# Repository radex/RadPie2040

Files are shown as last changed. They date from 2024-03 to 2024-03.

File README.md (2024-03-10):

# RadPie2040

A RP2040-based board, similar to [Raspberry Pi Pico H](https://www.raspberrypi.com/products/raspberry-pi-pico/), featuring:

- RP2040 microcontroller
- 16MB Flash
- breadboard-friendly pin headers with labels (+ debug header)
- USB-C connector
- BOOTSEL *and* RESET buttons
- **JLCPCB Assembly optimized**, 2-layer board
- KiCad 8 template, hierarchical schematic

**DISCLAIMER**: This board was designed as an exercise. It has not (yet) been manufactured and tested. Also, **I don't know what I'm doing**, this is like the third PCB I've designed. Don't use it lol.

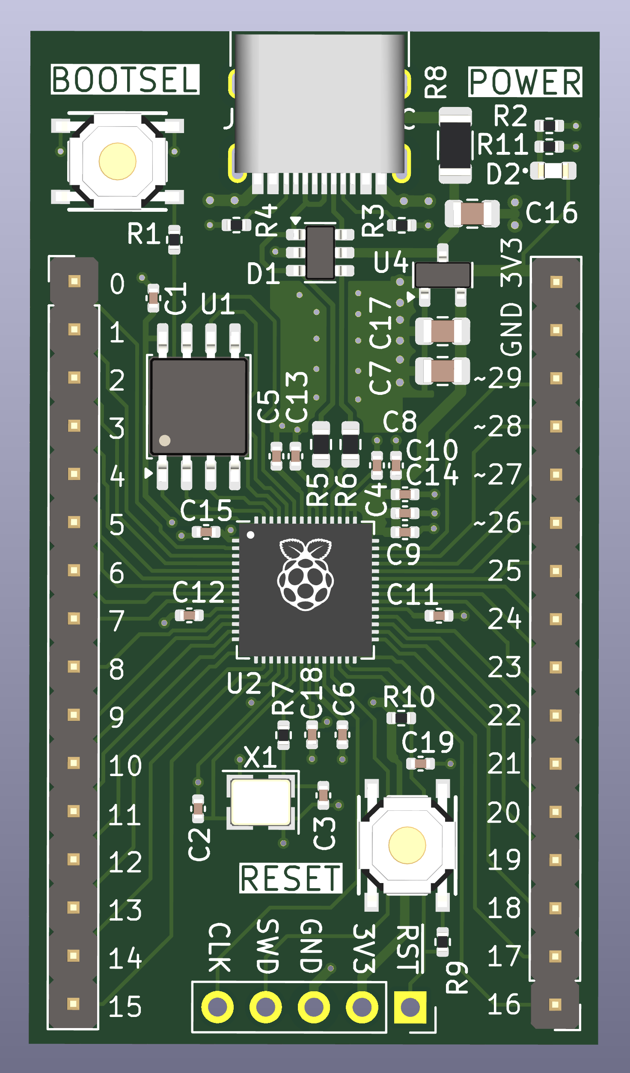
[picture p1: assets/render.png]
Top down render of the board
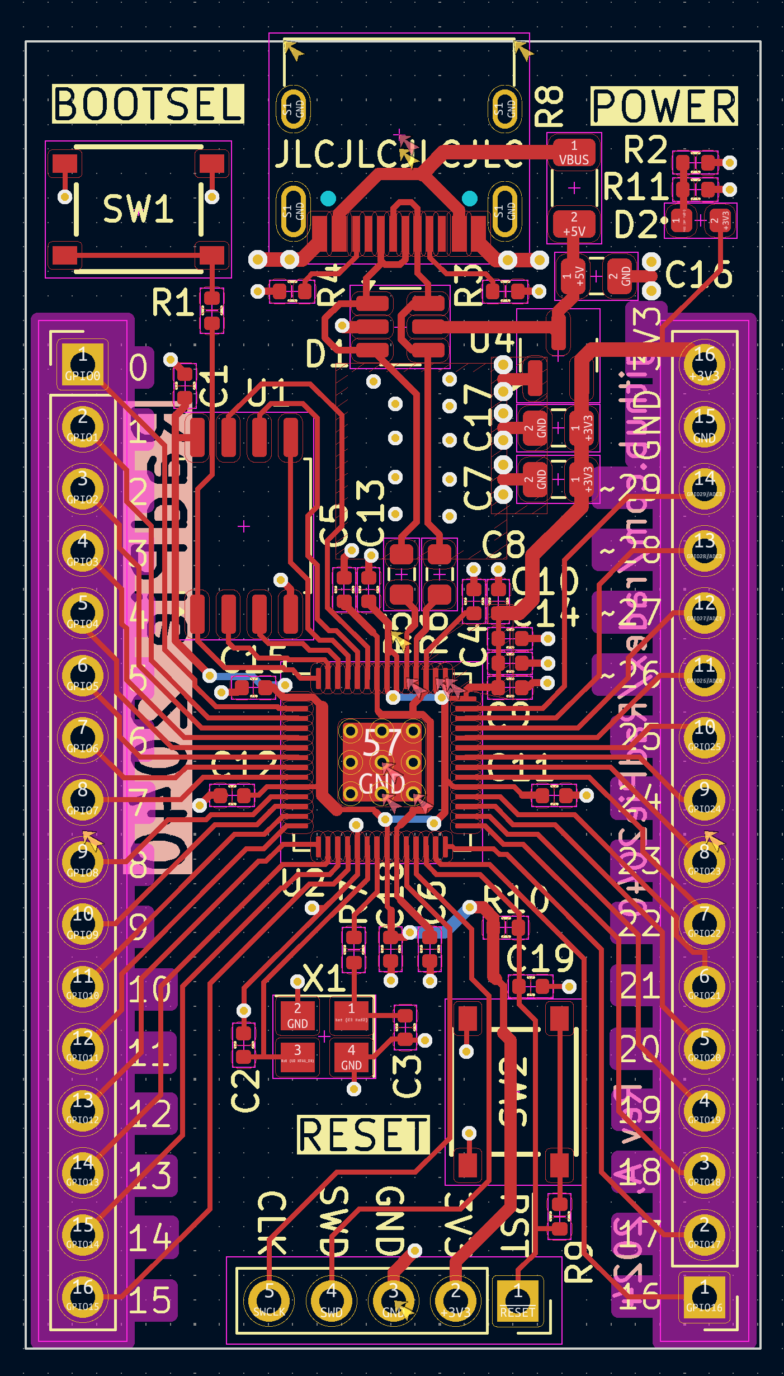
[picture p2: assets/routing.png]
PCB routing
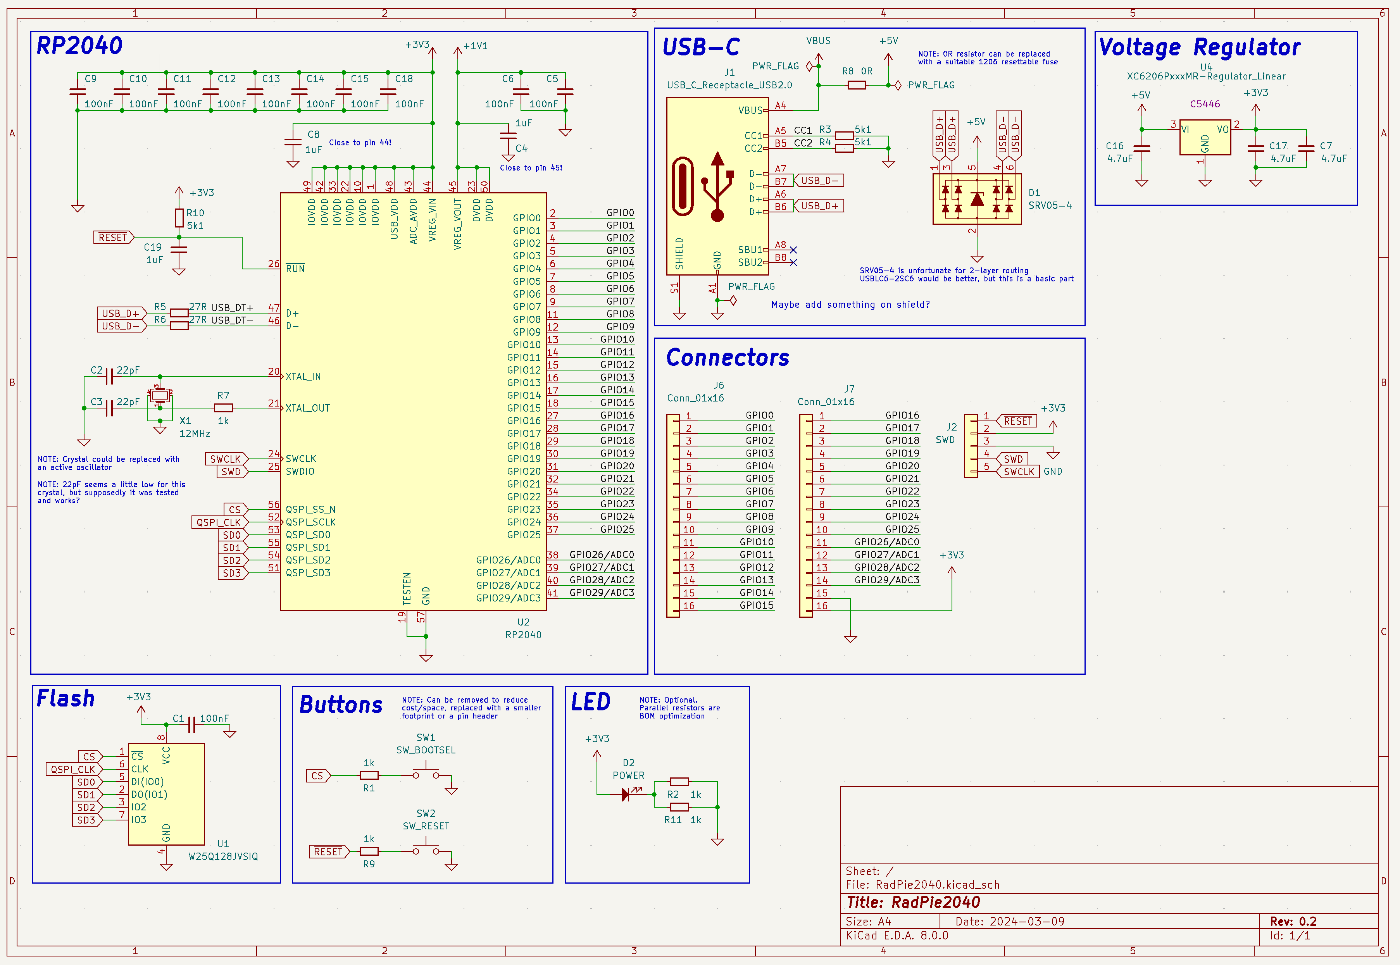
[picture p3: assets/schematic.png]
Schematics
|  |  |  |
| -- | -- | -- |

## Credits and learning resources

This project is a fork of [Sleepdealr/RP2040-designguide](https://github.com/Sleepdealr/RP2040-designguide). It bears little resemblance to the original, but it was a great starting point (and still contains some pieces of it).

I also took a lot of inspiration and knowledge from these YouTube videos:

- [MicroType Engineering - RP2040 KiCad 6 Hardware Design](https://www.youtube.com/watch?v=RNH-CL8GrF8)
- [Phil’s Lab - Raspberry Pi RP2040 Hardware Design](https://www.youtube.com/watch?v=X00Cm5LMNQk)

There's extra learning resources in the `Resources/` folder (copied from Sleepdealr's project).

## Components

This board is optimized to use JLCPCB Basic (or Extended Preferred) components as much as possible to make it cheap to manufacture at 2-5 pieces scale.

Some worth mentioning:

- Flash: C97521 - Winbond W25Q128JVSIQ - 128Mbit (16MB) NOR Flash
- Voltage Regulator: C5446 - XC6206
- Crystal: C9002 - 12MHz
- Buttons: C318884 - TS-1187A-B-A-B
- TVS diodes: C7420376 - SRV05-4

Most components are the same as in [Sleepdealr's design](https://github.com/Sleepdealr/RP2040-designguide). Differences: larger Flash, different TVS diodes, added buttons, power LED indicator, removed resettable fuse.

**Extended parts**: The only parts that are not on JLCPCB's Basic parts list (i.e. you'll pay $3 feeder fee per part) are the RP2040 and the USB-C connector. (Pin headers are not on the BOM, but you can add them).

## Customizability

Some things to consider:

- The 0Ω 1206 resistor is a placeholder for a resettable fuse. (There are none in JLC's Basic parts, but it's a good idea to have one)
- Flash storage and buttons could be replaced with smaller physical packages
- For size/cost/simplicity, you can remove buttons, USB, TVS, fuse placeholder, LED if you don't need them. You could even remove the crystal and rely on RP2040's ring oscillator if you don't need precise timing or max performance

## TODO

- Have this board manufactured, see if it works!
- I'm concerned about the crystal, it seems to me that layout and loading capacitors could be better, but they can be finnicky, and Sleepdealr's design works, so I didn't change anything.
- I'm thinking of designing a smaller version, optimized for use as a module with carrier boards (using 1mm pitch pin headers, not castellated holes like the original Pico for cost reasons)

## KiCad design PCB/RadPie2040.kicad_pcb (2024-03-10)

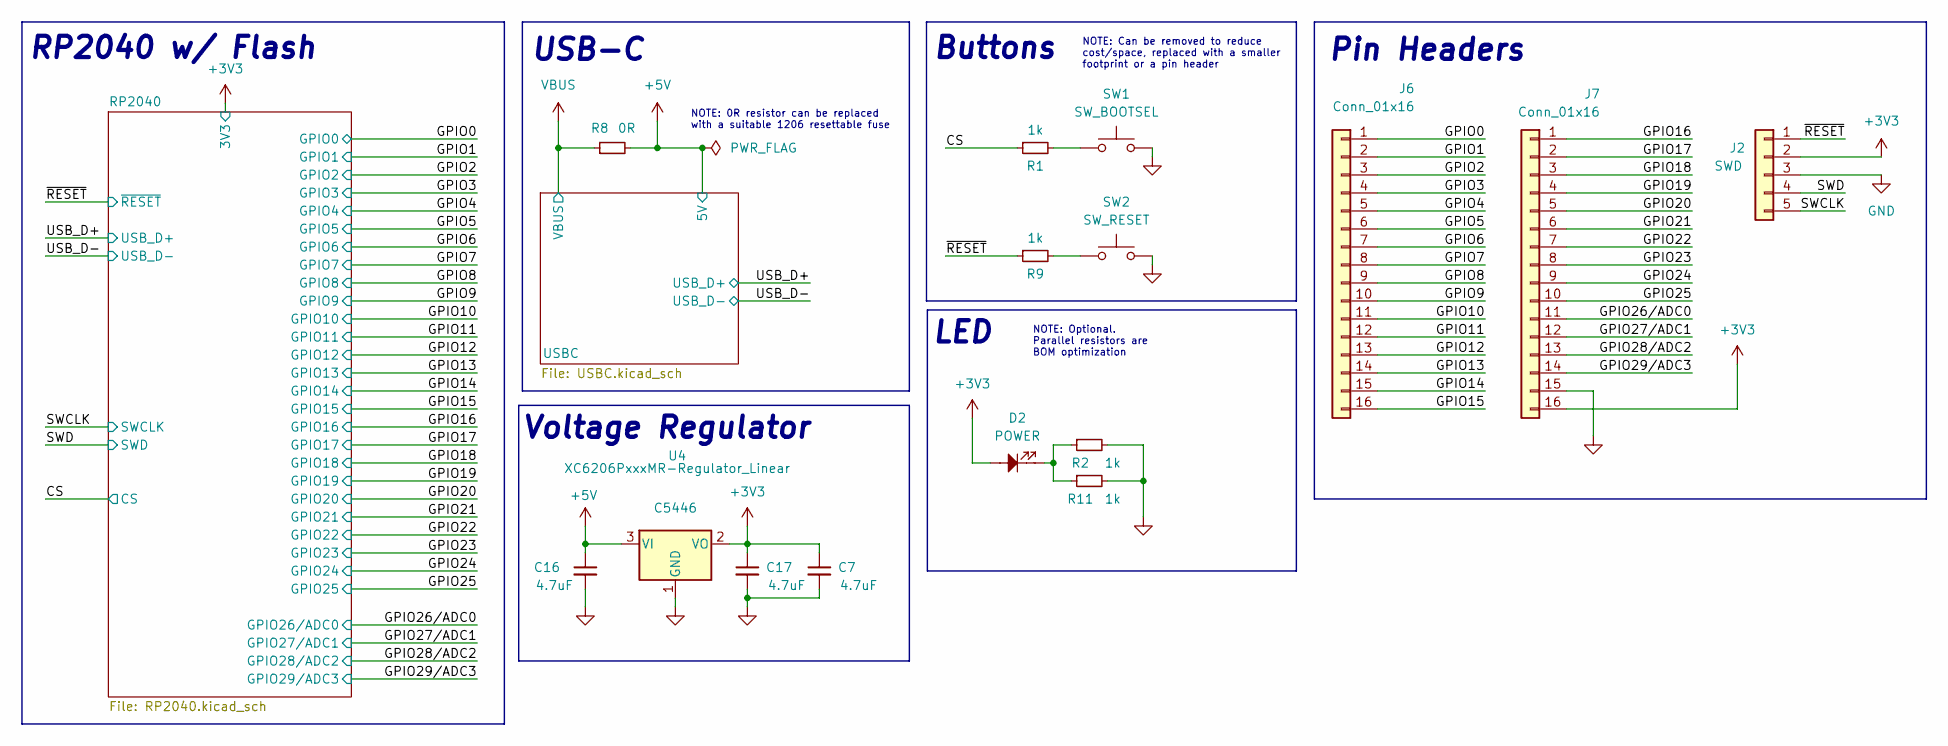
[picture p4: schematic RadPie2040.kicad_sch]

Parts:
C7, C16, C17: 4.7uF; C_0805_2012Metric; LCSC C1779
D2: POWER; LED_0603_1608Metric_Dot; LCSC C2286
J2: SWD; PinSocket_1x05_P2.54mm_Vertical
J6, J7: Conn_01x16; PinHeader_1x16_P2.54mm_Vertical
R1, R2, R9, R11: 1k; R_0402_1005Metric; LCSC C11702
R8: 0R; R_1206_3216Metric; LCSC C17888
SW1: SW_BOOTSEL; TS-1187A-B-A-B; LCSC C318884
SW2: SW_RESET; TS-1187A-B-A-B; LCSC C318884
U4: XC6206PxxxMR-Regulator_Linear; SOT-23; LCSC C5446

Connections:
+3V3: C7.1, C17.1, D2.2, J2.2, J7.16, U4.2 (VO); also elsewhere on the board
+5V: C16.1, R8.2, U4.3 (VI); also elsewhere on the board
/CS: R1.1; also elsewhere on the board
/GPIO0: J6.1; also elsewhere on the board
/GPIO1: J6.2; also elsewhere on the board
/GPIO2: J6.3; also elsewhere on the board
/GPIO3: J6.4; also elsewhere on the board
/GPIO4: J6.5; also elsewhere on the board
/GPIO5: J6.6; also elsewhere on the board
/GPIO6: J6.7; also elsewhere on the board
/GPIO7: J6.8; also elsewhere on the board
/GPIO8: J6.9; also elsewhere on the board
/GPIO9: J6.10; also elsewhere on the board
/GPIO10: J6.11; also elsewhere on the board
/GPIO11: J6.12; also elsewhere on the board
/GPIO12: J6.13; also elsewhere on the board
/GPIO13: J6.14; also elsewhere on the board
/GPIO14: J6.15; also elsewhere on the board
/GPIO15: J6.16; also elsewhere on the board
/GPIO16: J7.1; also elsewhere on the board
/GPIO17: J7.2; also elsewhere on the board
/GPIO18: J7.3; also elsewhere on the board
/GPIO19: J7.4; also elsewhere on the board
/GPIO20: J7.5; also elsewhere on the board
/GPIO21: J7.6; also elsewhere on the board
/GPIO22: J7.7; also elsewhere on the board
/GPIO23: J7.8; also elsewhere on the board
/GPIO24: J7.9; also elsewhere on the board
/GPIO25: J7.10; also elsewhere on the board
/GPIO26/ADC0: J7.11; also elsewhere on the board
/GPIO27/ADC1: J7.12; also elsewhere on the board
/GPIO28/ADC2: J7.13; also elsewhere on the board
/GPIO29/ADC3: J7.14; also elsewhere on the board
/SWCLK: J2.5; also elsewhere on the board
/SWD: J2.4; also elsewhere on the board
/~RESET: J2.1, R9.1; also elsewhere on the board
GND: C7.2, C16.2, C17.2, J2.3, J7.15, R2.2, R11.2, SW1.1, SW2.1, U4.1 (GND); also elsewhere on the board
unnamed: D2.1, R2.1, R11.1
unnamed: R1.2, SW1.2
unnamed: R9.2, SW2.2
VBUS: R8.1; also elsewhere on the board

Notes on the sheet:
NOTE: Optional. Parallel resistors are BOM optimization
NOTE: 0R resistor can be replaced with a suitable 1206 resettable fuse
NOTE: Can be removed to reduce cost/space, replaced with a smaller footprint or a pin header
RP2040 w/ Flash
Voltage Regulator
LED
USB-C
Buttons
Pin Headers

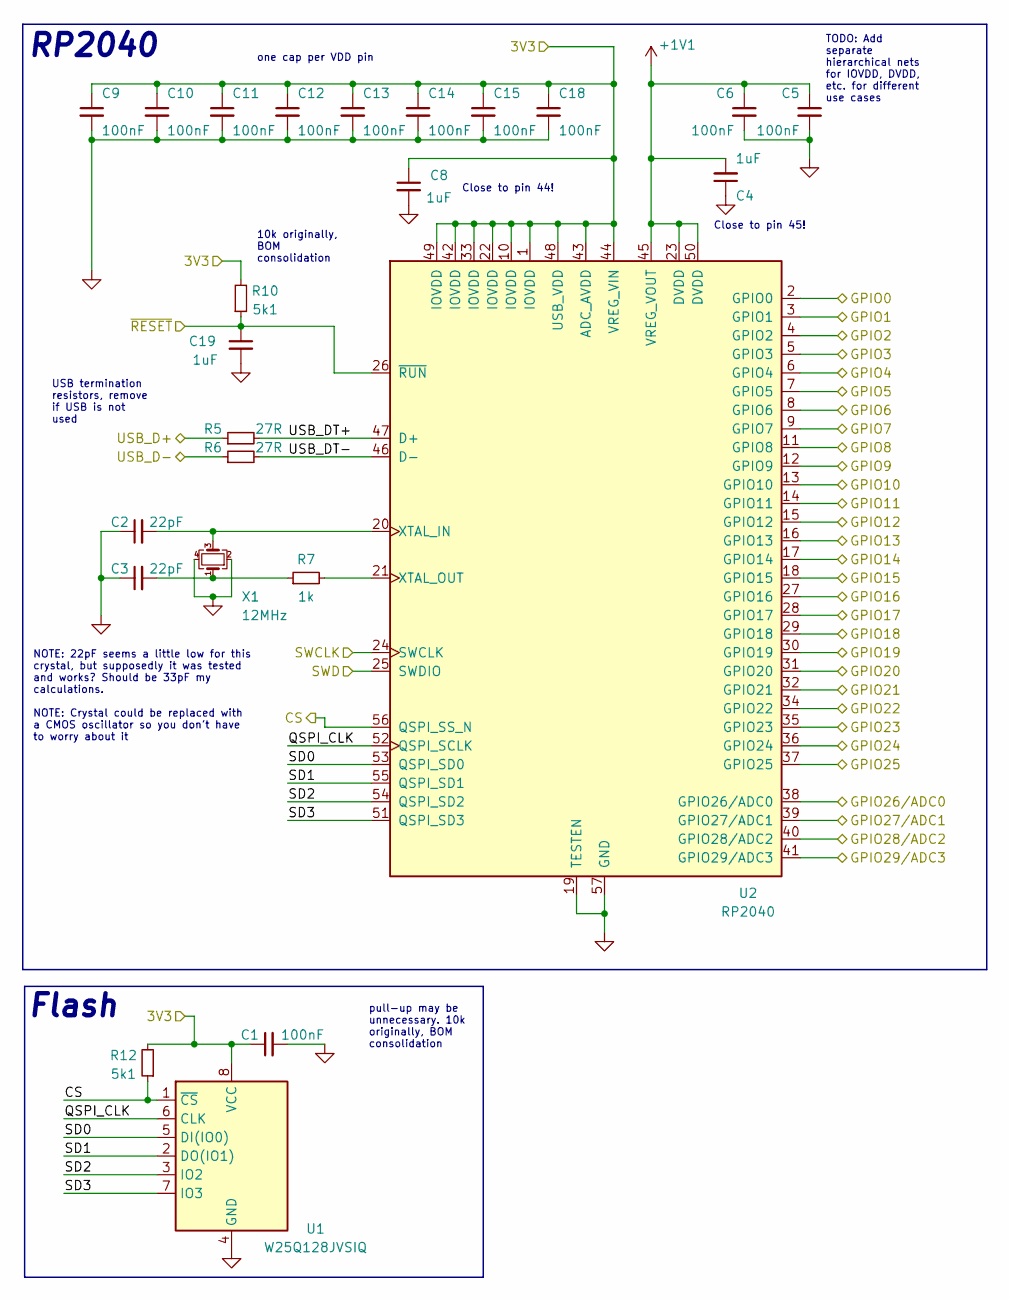
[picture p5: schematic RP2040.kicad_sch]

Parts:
C1, C5, C6, C9, C10, C11, C12, C13, C14, C15, C18: 100nF; C_0402_1005Metric; LCSC C1525
C2, C3: 22pF; C_0402_1005Metric; LCSC C1555
C4, C8, C19: 1uF; C_0402_1005Metric; LCSC C52923
R5, R6: 27R; R_0603_1608Metric; LCSC C25190
R7: 1k; R_0402_1005Metric; LCSC C11702
R10, R12: 5k1; R_0402_1005Metric; LCSC C25905
U1: W25Q128JVSIQ; SOIC-8_5.23x5.23mm_P1.27mm; LCSC C97521
U2: RP2040; RP2040-QFN-56; LCSC C2040
X1: 12MHz; Crystal_SMD_3225-4Pin_3.2x2.5mm; LCSC C9002

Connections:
+1V1: C4.2, C5.1, C6.1, U2.23 (DVDD), U2.45 (VREG_VOUT), U2.50 (DVDD)
+3V3: C1.1, C8.1, C9.1, C10.1, C11.1, C12.1, C13.1, C14.1, C15.1, C18.1, R10.2, R12.2, U1.8 (VCC), U2.1 (IOVDD), U2.10 (IOVDD), U2.22 (IOVDD), U2.33 (IOVDD), U2.42 (IOVDD), U2.43 (ADC_AVDD), U2.44 (VREG_VIN), U2.48 (USB_VDD), U2.49 (IOVDD); also elsewhere on the board
/CS: R12.1, U1.1 (~CS), U2.56 (QSPI_SS_N); also elsewhere on the board
/GPIO0: U2.2 (GPIO0); also elsewhere on the board
/GPIO1: U2.3 (GPIO1); also elsewhere on the board
/GPIO2: U2.4 (GPIO2); also elsewhere on the board
/GPIO3: U2.5 (GPIO3); also elsewhere on the board
/GPIO4: U2.6 (GPIO4); also elsewhere on the board
/GPIO5: U2.7 (GPIO5); also elsewhere on the board
/GPIO6: U2.8 (GPIO6); also elsewhere on the board
/GPIO7: U2.9 (GPIO7); also elsewhere on the board
/GPIO8: U2.11 (GPIO8); also elsewhere on the board
/GPIO9: U2.12 (GPIO9); also elsewhere on the board
/GPIO10: U2.13 (GPIO10); also elsewhere on the board
/GPIO11: U2.14 (GPIO11); also elsewhere on the board
/GPIO12: U2.15 (GPIO12); also elsewhere on the board
/GPIO13: U2.16 (GPIO13); also elsewhere on the board
/GPIO14: U2.17 (GPIO14); also elsewhere on the board
/GPIO15: U2.18 (GPIO15); also elsewhere on the board
/GPIO16: U2.27 (GPIO16); also elsewhere on the board
/GPIO17: U2.28 (GPIO17); also elsewhere on the board
/GPIO18: U2.29 (GPIO18); also elsewhere on the board
/GPIO19: U2.30 (GPIO19); also elsewhere on the board
/GPIO20: U2.31 (GPIO20); also elsewhere on the board
/GPIO21: U2.32 (GPIO21); also elsewhere on the board
/GPIO22: U2.34 (GPIO22); also elsewhere on the board
/GPIO23: U2.35 (GPIO23); also elsewhere on the board
/GPIO24: U2.36 (GPIO24); also elsewhere on the board
/GPIO25: U2.37 (GPIO25); also elsewhere on the board
/GPIO26/ADC0: U2.38 (GPIO26/ADC0); also elsewhere on the board
/GPIO27/ADC1: U2.39 (GPIO27/ADC1); also elsewhere on the board
/GPIO28/ADC2: U2.40 (GPIO28/ADC2); also elsewhere on the board
/GPIO29/ADC3: U2.41 (GPIO29/ADC3); also elsewhere on the board
/RP2040/QSPI_CLK: U1.6 (CLK), U2.52 (QSPI_SCLK)
/RP2040/SD0: U1.5 (DI(IO0)), U2.53 (QSPI_SD0)
/RP2040/SD1: U1.2 (DO(IO1)), U2.55 (QSPI_SD1)
/RP2040/SD2: U1.3 (IO2), U2.54 (QSPI_SD2)
/RP2040/SD3: U1.7 (IO3), U2.51 (QSPI_SD3)
/RP2040/USB_DT+: R5.2, U2.47 (D+)
/RP2040/USB_DT-: R6.2, U2.46 (D-)
/SWCLK: U2.24 (SWCLK); also elsewhere on the board
/SWD: U2.25 (SWDIO); also elsewhere on the board
/USB_D+: R5.1; also elsewhere on the board
/USB_D-: R6.1; also elsewhere on the board
/~RESET: C19.1, R10.1, U2.26 (~RUN); also elsewhere on the board
GND: C1.2, C2.1, C3.1, C4.1, C5.2, C6.2, C8.2, C9.2, C10.2, C11.2, C12.2, C13.2, C14.2, C15.2, C18.2, C19.2, U1.4 (GND), U2.19 (TESTEN), U2.57 (GND), X1.2, X1.4; also elsewhere on the board
unnamed: C3.2, R7.1, X1.1
unnamed: C2.2, U2.20 (XTAL_IN), X1.3
unnamed: R7.2, U2.21 (XTAL_OUT)

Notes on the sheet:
USB termination resistors, remove if USB is not used
Close to pin 45!
one cap per VDD pin
NOTE: 22pF seems a little low for this crystal, but supposedly it was tested and works? Should be 33pF my calculations. NOTE: Crystal could be replaced with a CMOS oscillator so you don't have to worry about it
10k originally, BOM consolidation
TODO: Add separate hierarchical nets for IOVDD, DVDD, etc. for different use cases
pull-up may be unnecessary. 10k originally, BOM consolidation
Close to pin 44!
RP2040
Flash

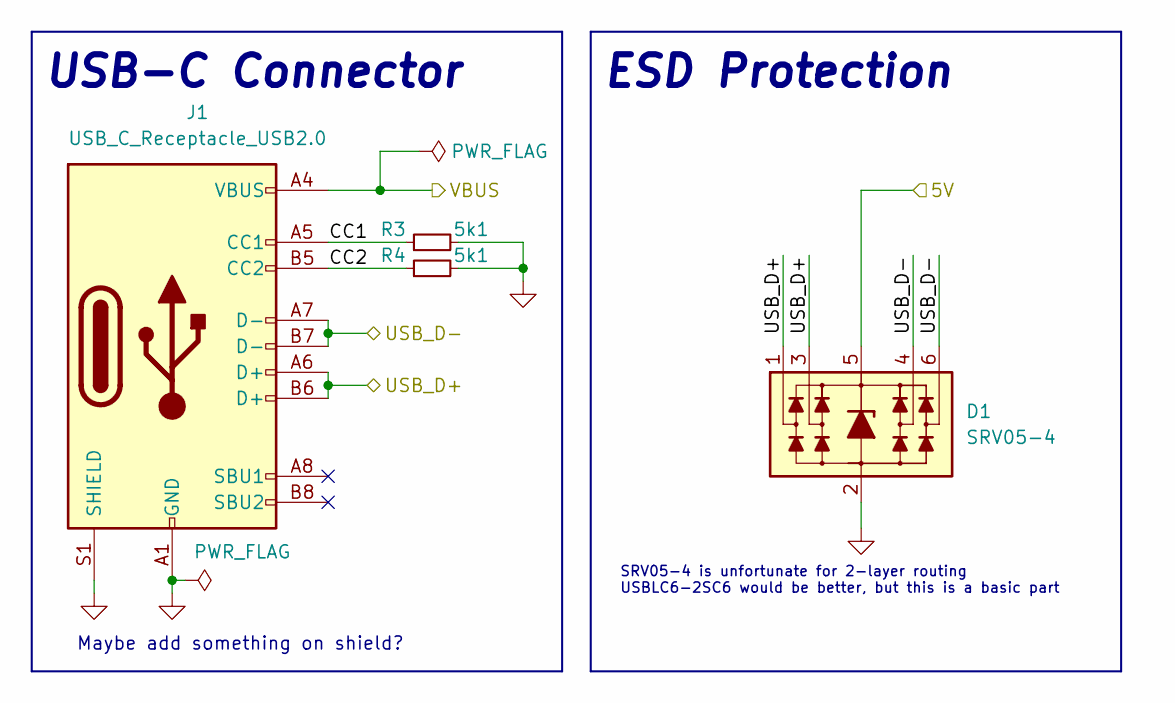
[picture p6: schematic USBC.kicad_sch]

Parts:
D1: SRV05-4; SOT-23-6; LCSC C7420376
J1: USB_C_Receptacle_USB2.0; USB_C_Receptacle_HRO_TYPE-C-31-M-12; LCSC C165948
R3, R4: 5k1; R_0402_1005Metric; LCSC C25905

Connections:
+5V: D1.5 (VP); also elsewhere on the board
/USBC/CC1: J1.A5 (CC1), R3.1
/USBC/CC2: J1.B5 (CC2), R4.1
/USB_D+: D1.1 (L1), D1.3 (L2), J1.A6 (D+), J1.B6 (D+); also elsewhere on the board
/USB_D-: D1.4 (L3), D1.6 (L4), J1.A7 (D-), J1.B7 (D-); also elsewhere on the board
GND: D1.2 (VN), J1.A1 (GND), J1.A12 (GND), J1.B1 (GND), J1.B12 (GND), J1.S1 (SHIELD), R3.2, R4.2; also elsewhere on the board
VBUS: J1.A4 (VBUS), J1.A9 (VBUS), J1.B4 (VBUS), J1.B9 (VBUS); also elsewhere on the board

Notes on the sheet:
USB-C Connector
SRV05-4 is unfortunate for 2-layer routing USBLC6-2SC6 would be better, but this is a basic part
ESD Protection
Maybe add something on shield?

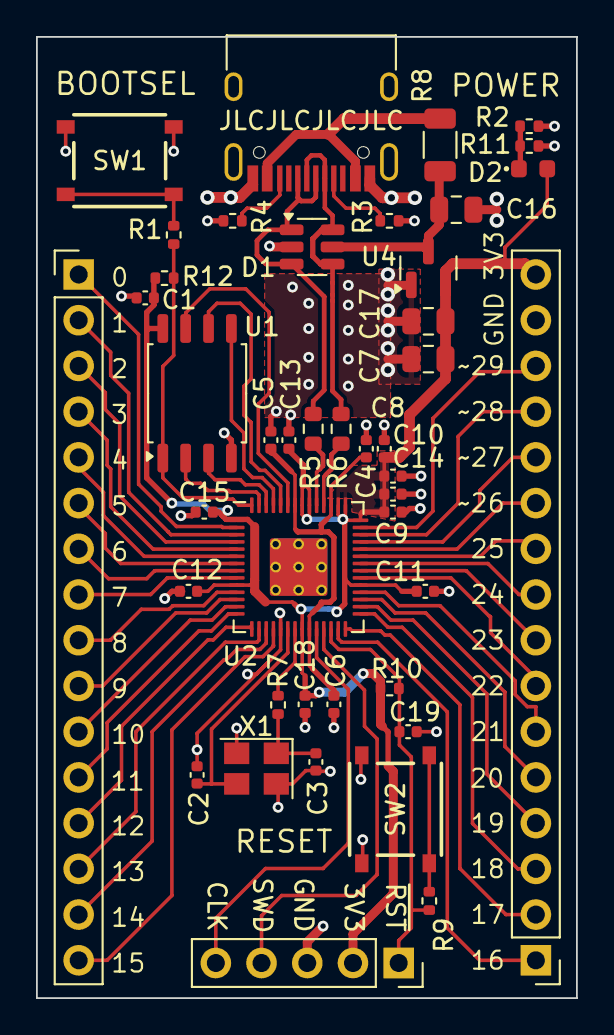
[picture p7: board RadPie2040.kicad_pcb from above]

Board: 2 copper layers, 30.0 x 53.4 mm, 43 parts (0 on the bottom side), 56 nets.

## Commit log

2024-03-10 Add pull-up for Flash, just in case
    [RadPie2040.kicad_pcb, RadPie2040.kicad_sch]
2024-03-10 Refactor schematic to be hierarchical
    [RP2040.kicad_sch, RadPie2040.kicad_pcb, RadPie2040.kicad_sch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]
2024-03-10 jlcpcb production fixes
    [RadPie2040.kicad_pcb, USBC.kicad_sch]
